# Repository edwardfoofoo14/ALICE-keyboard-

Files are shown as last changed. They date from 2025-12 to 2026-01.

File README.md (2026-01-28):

# SELENE

This is my SELENE, my project for the Blueprint Hack Club event!

The board uses an ALICE layout with added F rows, it is inspired by Dante from Devil May Cry (my favourite character). It uses a stacked acrylic format which I took inspiration from Adelheid, and Arisu which are both Alice keyboards. The stacked acrylic mentioned is a collection of 10, 3mm, A3 sized, machine cut acrylic plates screwed together, I chose this method in particular because the material will generate a "clackier" sound profile and is also more cost effective that other methods.

---

## Files Included
- PCB  
- Plate  
- Case 
- Simulation code and diagram 

Cool graphics showing each layers of the acrylic
kbgif

---

## PCB

Note: it is quite rudimentary because a keyboard isn't the most complicated thing in the world.

PCB Layout

Overview of the schematic

Schematic

---

## Plate

Note: The plate will be shinier in real life :D

Plate

---

## Case

Case

Note:
- Both the plate and case are provided as DXF files, and dimensions may still be adjusted.

---

## Parts Required
- 10x A3 acrylic sheets (3 mm)
- 1x A3 acrylic sheet (2 mm)
- Poron gaskets (3 mm thickness)
- 6x M5 x 35 mm screws
- 6x M5 nuts

---

## Cutting Instructions
- Use the DXF files located in the dxf folder
- Cut plates 1 to 10 from the 3 mm acrylic
- Cut the main plate from the 2 mm acrylic

---

## Assembly Instructions
1. Stack the numbered plates from bottom to top  
2. On plate 2:
   - Secure the USB C breakout board
   - Add Poron gaskets to the protruding sections
3. Place the keyboard plate on top with the PCB already attached (switches snapped into respective holes in the plate)
4. Apply adhesive Poron gaskets again on the top surface
5. Continue stacking plates 3 to 10
6. Secure the entire assembly using the screws, ideally with the nuts on the bottom side. The screws should skewer through the whole width of the keyboard.

---

## Important Notes
An important thing to note would be to afix your stabilisers switches to the plate and PCB before assembly as there is nothing to join the pcb and plate together. Also for plate 2 and 10 there are my personal designs, you can add your own if you want or just make sure you remove it if you don't want my design.

---

## Simulation
The Wokwi simulation follows the exact ESP32 pinout shown in the KiCad schematic:

https://github.com/user-attachments/assets/cd191653-9d43-4bff-b9b6-e710f8436f32

---

## Wiring
The wiring is extremely simple. Just connect the cables between the keyboard PCB and USB-C breakout board following the labels on the silkscreen

Depending on the type of USB-C breakout boards used, CC1 and CC2 pins may or may not require 5.1kΩ pull down. The Sparkfun boards have two resistors that are already soldered.
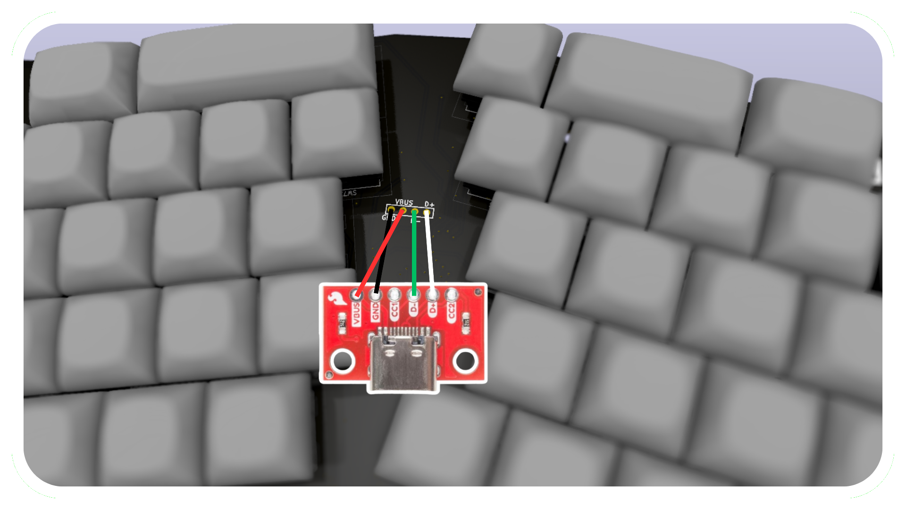
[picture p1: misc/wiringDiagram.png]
Wiring Diagram


## Bill of Material

Note: The prices in USD are converted as of 7 January 2026 and prices may fluctuate

| Category | Item Name | Part Number / File Name | Link | Vendor | Quantity | Total Price (USD) |
|---|---|---|---|---|---|---|
| Electronics | ESP32-S3-WROOM-1-N16-R2 | ESP32-S3-WROOM-1-N16-R2 | [Link](https://shopee.com.my/ESP32-S3-ESP32-S3-WROOM-1-1U-ESP32-S3-MINI-1U-4MB-8MB-16MB-N4-N4R2-N4R8-N8-N8R2-N8R8-N16-N16R2-N16R8-WiFi-Ble-5.0-Module-i.1649836180.431738840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) | Shopee | 1x | 6.53 |
| Electronics | SK6812 MINI-E | | [Link](https://shopee.com.my/100PCS-SK6812-MINI-E-RGB-(Similar-WS2812B)-SK6812-3228-SMD-Pixels-LED-Chip-Individually-Addressable-Full-Color-DC-5V-i.201200871.29163981070) | Shopee | 100x | 2.80 |
| Electronics | 1206 100nF Capacitor | | [Link](https://shopee.com.my/100pcs-1206-3216-SMD-Chip-Ceramic-Capacitor-1NF-2.2NF-10NF-22NF-100NF-1uF-2.2uF-4.7uF-10uF-22uF-47uF-100uF-6.3V-10V-16V-25V-50V-i.1649836180.51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) | Shopee | 100x | 0.35 |
| Electronics | Hotswap Sockets | | [Link](https://shopee.com.my/redsunaa-Hot-Swap-Socket-For-Kailh-CPG151101S11-for-Mechanical-Keyboard-Switch-Pcb-Base-i.1336977141.27113734076) | Shopee | 100x | 9.95 |
| Electronics | USB-C Breakout Board | | [Link](https://shopee.com.my/Pcbfun-USB-Type-C-Connector-Board-DIY-3.1-Serial-Basic-Breakout-Female-Connector-Type-C-Breakout-Board-for-Data-Line-Wire-Cable-Transfer-i.1754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) | Shopee | 1x | 0.80 |
| Production | PCB | gerbers.zip | | JLCPCB | 1x | 23.00 |
| Fasteners | M5*35mm Hex Screws | | [Link](https://shopee.com.my/Button-Head-Screw-Black-304-Stainless-Steel-SHINY-SURFACE-Allen-Bolt-DIN7380-Skru-Ellenkey-Hex-Socket-Button-Head-Screw-ISO7380-SUS-Black-304-S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) | Shopee | 10x | 3.55 |
| Fasteners | M5 Nuts | | [Link](https://shopee.com.my/-HKH-Hexagon-Nut-M2-M2.5-M2.6-M3-M3.5-M4-M5-M6-M8-M10-M12-Black-arbon-Steel-Hexagon-Nut-Screw-Cap-i.1435573023.27623483039) | Shopee | 50x | 0.55 |
| Misc | Stabilisers | | [Link](https://shopee.com.my/Kelowna-Link-Studio-PCB-Screw-in-Stabilizers-Mechanical-Keyboard-i.71961069.12272946569) | Shopee | 1x | 7.40 |
| Misc | Gaskets | | [Link](https://shopee.com.my/Gasket-Strip-Poron-black-only-i.1034684783.25753214842) | Shopee | 1x | 3.20 |
| Misc | Switches | | [Link](https://shopee.com.my/Outemu-Honey-Peach-Silent-Linear-Switch-for-Mechanical-Keyboards-i.72068395.11794425429) | Shopee | 82x | 22.90 |
| Shipping | PCB Shipping | E-POST | | JLCPCB | 1x | 9.87 |
| Shipping | Switches Shipping | SPX Express International | | Shopee | 1x | 0.00 |
| Shipping | Electronics Shipping | SPX Express International | | Shopee | 4x | 5.20 |
| Shipping | Fasteners Shipping | SPX Express International | | Shopee | 2x | 2.60 |
| Shipping | Gaskets Shipping | SPX Express | | Shopee | 1x | 1.30 |
| | | | *Do take note this list excludes some parts that hack club isn't paying for, required parts to build the keyboard is in the excluded list in the readme* | | **Grand Total:** | **100.00** |

## Excluded Items

- Keycaps
- Diodes
- 4.7k resistor
- 10uF capacitors
- A3 3mm acrylic plates

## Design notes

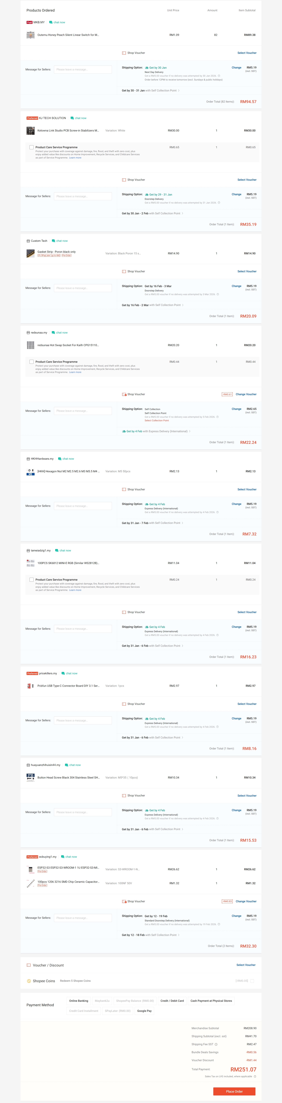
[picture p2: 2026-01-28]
cartScreenshots/shopeeCart.jpeg

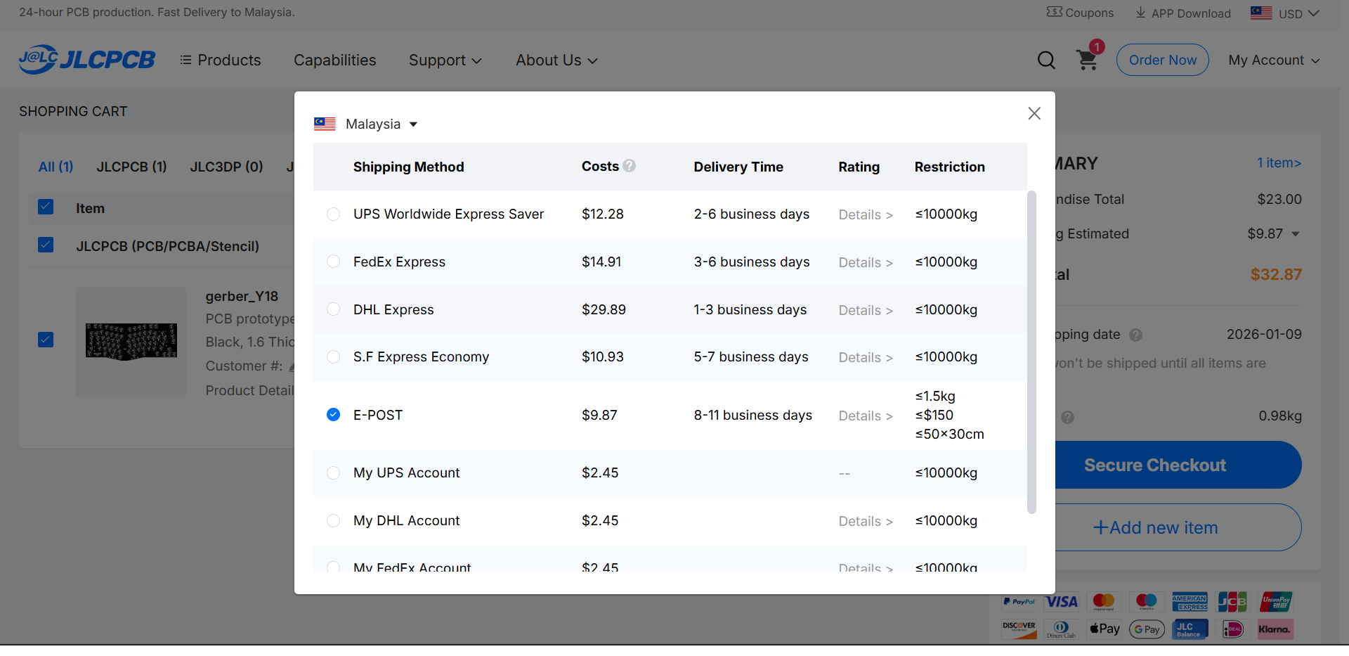
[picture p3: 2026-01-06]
cartScreenshots/shippingOptions.png

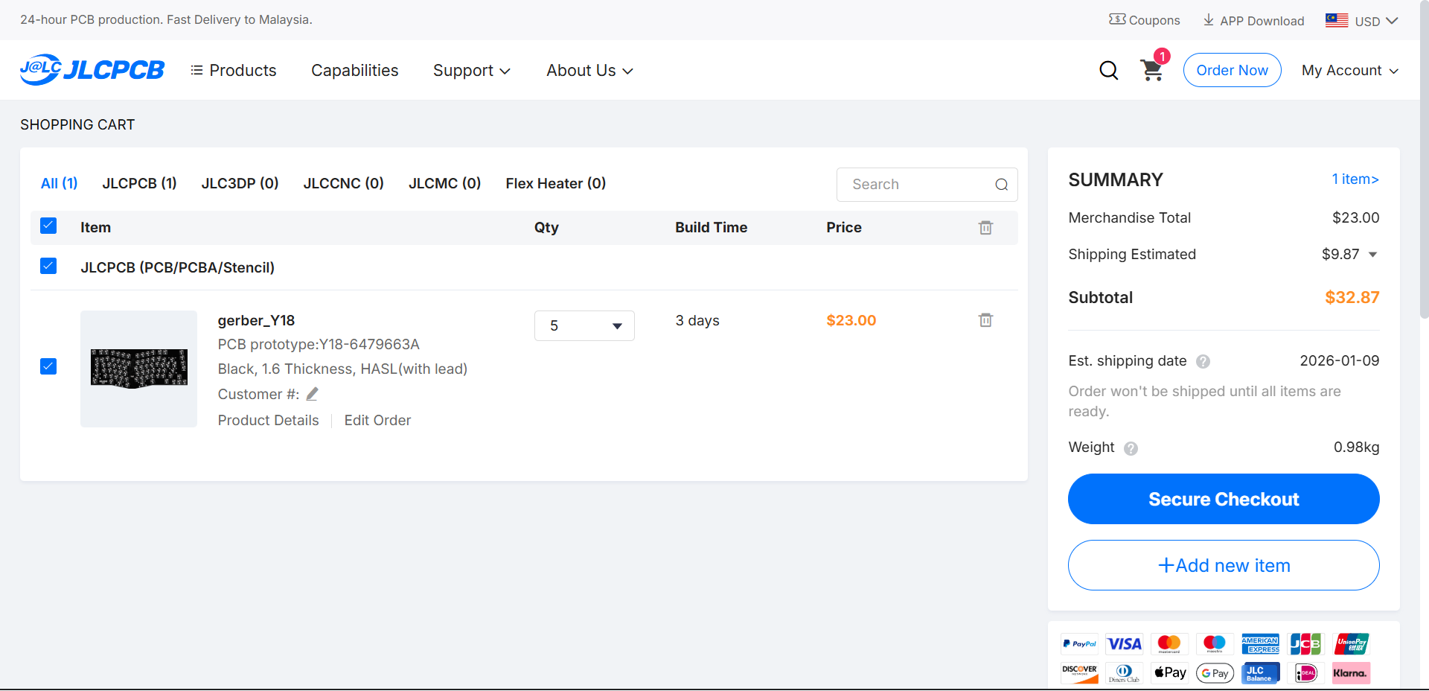
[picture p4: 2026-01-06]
cartScreenshots/JLCPCBCart.png

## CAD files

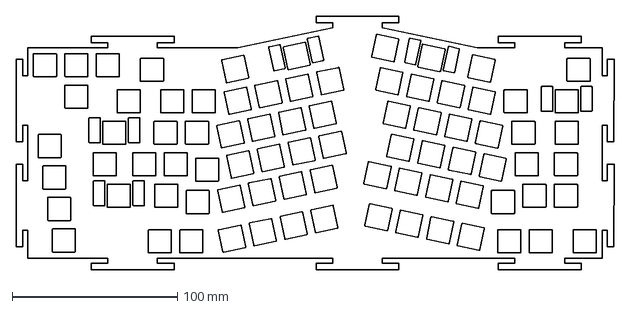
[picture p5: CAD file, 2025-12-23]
production/LaserCut/MAINPLATE.dxf
361.9 x 153.3 mm

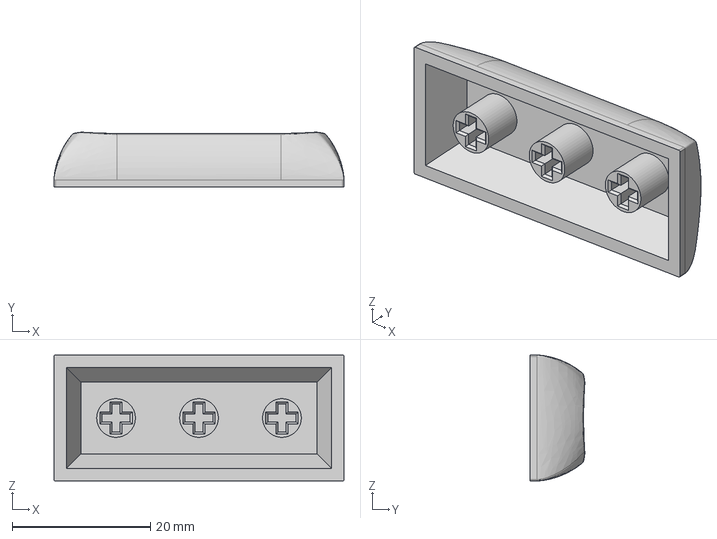
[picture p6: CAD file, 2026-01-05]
PCB/3d/keycap/DSA_2.25u.step
42.0 x 7.91 x 18.2 mm

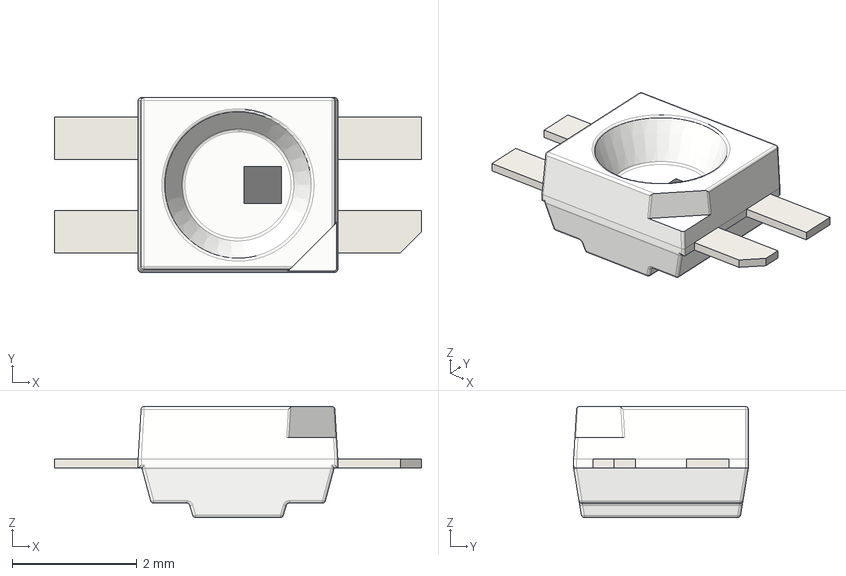
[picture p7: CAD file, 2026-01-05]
PCB/3d/LED_SK6812MINI-E.step
5.88 x 2.80 x 1.78 mm

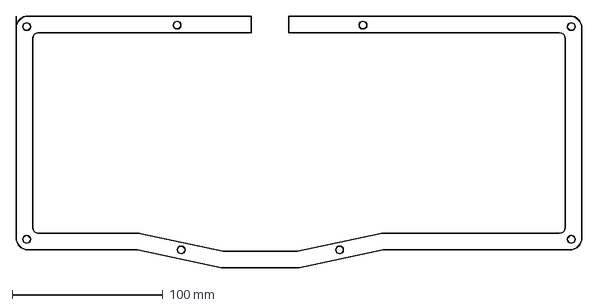
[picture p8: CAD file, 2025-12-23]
production/LaserCut/plate 3.dxf
375.0 x 167.0 mm

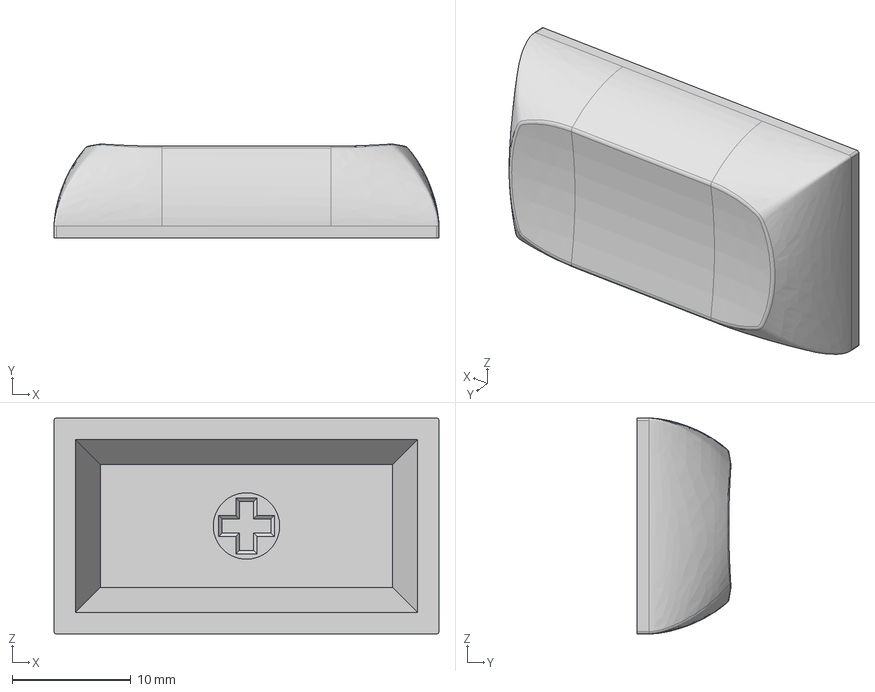
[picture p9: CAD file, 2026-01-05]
PCB/3d/keycap/DSA_1.75u.step
32.5 x 7.91 x 18.2 mm

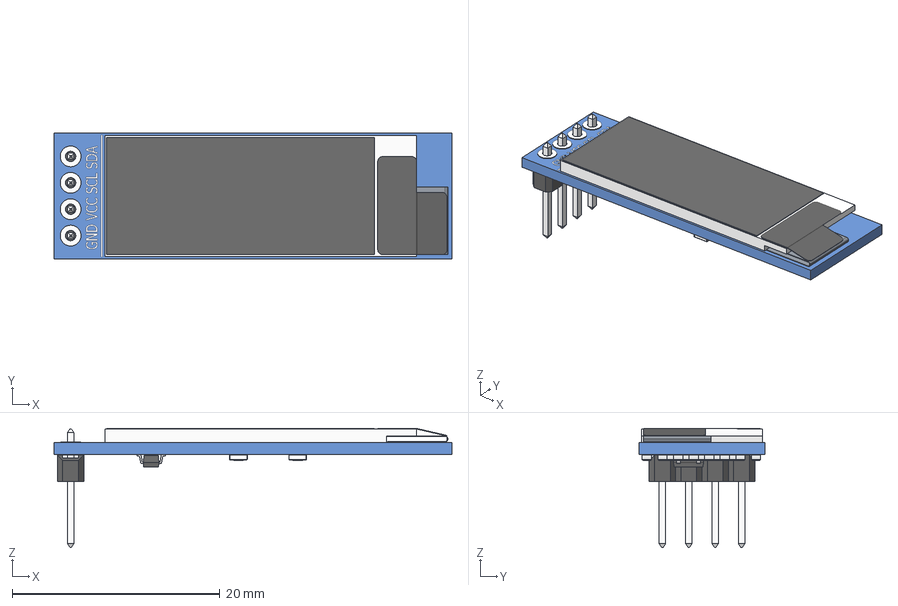
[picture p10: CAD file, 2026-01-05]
PCB/3d/OLED_0.91_128x32.stp
38.3 x 12.1 x 11.5 mm
OLED_0.91_128x32
Pin Header 4 x 1 TH 2.54mm Pitch
RESC-0603 x 13
2SD0601A

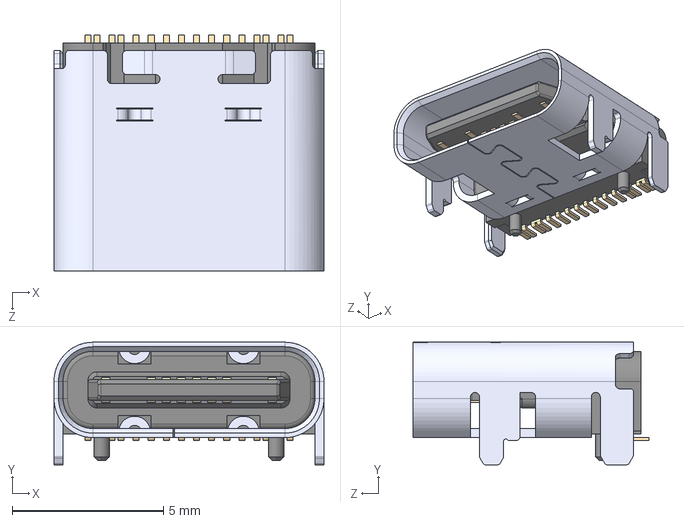
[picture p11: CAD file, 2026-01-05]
PCB/3d/CQ-USB-C16PSMT01.step
8.94 x 4.06 x 7.81 mm

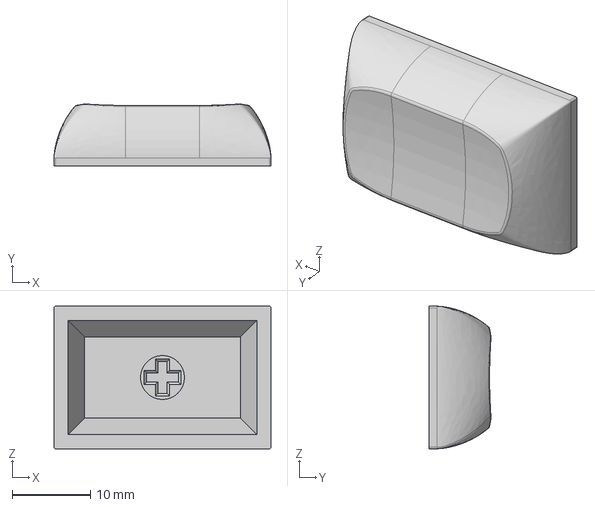
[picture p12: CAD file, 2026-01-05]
PCB/3d/keycap/DSA_1.5u.step
27.7 x 7.91 x 18.2 mm

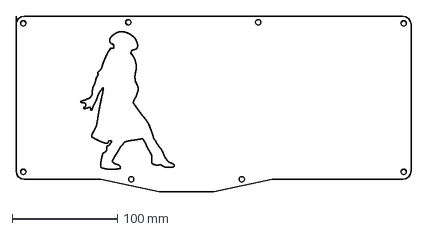
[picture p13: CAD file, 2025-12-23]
production/LaserCut/plate 2.dxf
375.0 x 167.0 mm

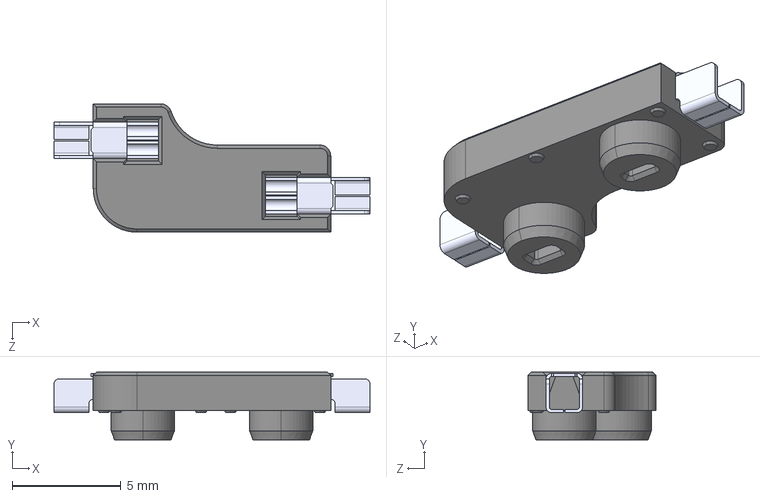
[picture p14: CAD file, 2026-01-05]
PCB/3d/kailhSocket.STEP
14.5 x 3.10 x 5.89 mm

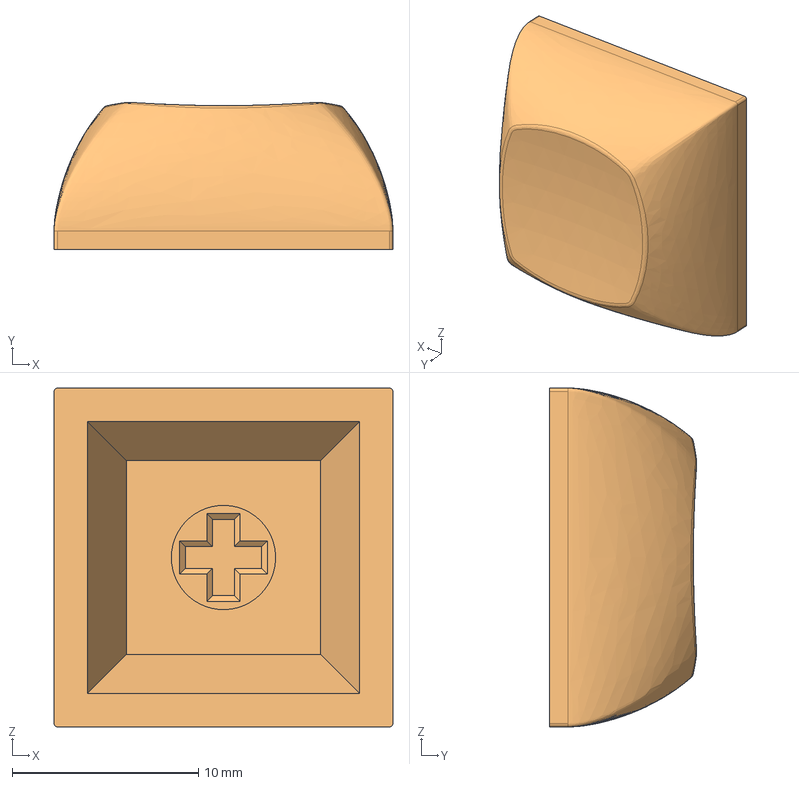
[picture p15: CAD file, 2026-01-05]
PCB/3d/keycap/DSA_1u.step
18.2 x 7.91 x 18.2 mm

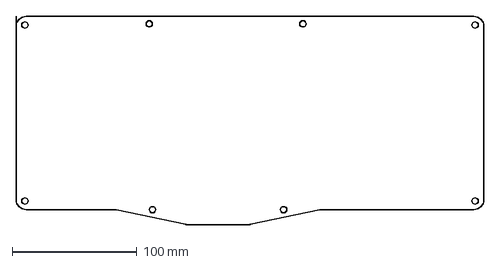
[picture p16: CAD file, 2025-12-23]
production/LaserCut/plate 1.dxf
375.0 x 167.0 mm

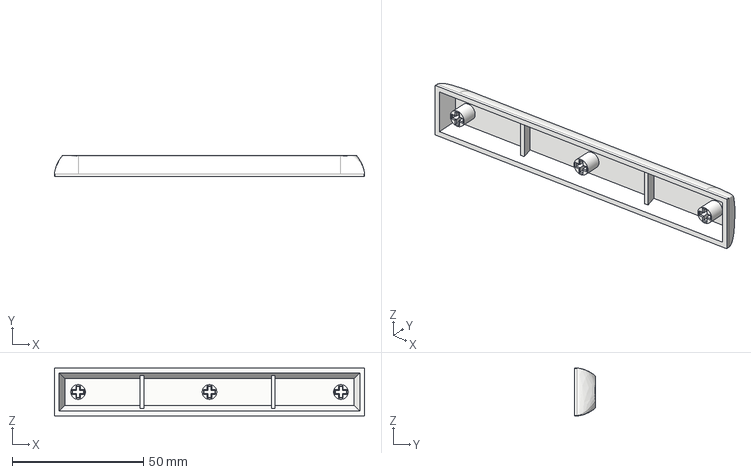
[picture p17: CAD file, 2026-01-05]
PCB/3d/keycap/DSA_6.25u.step
118.0 x 8.00 x 18.2 mm

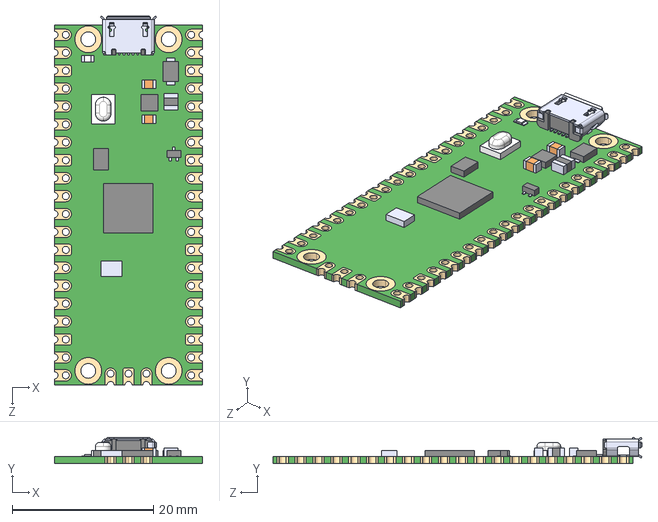
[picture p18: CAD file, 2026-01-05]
PCB/3d/RASPBERRY_PI_PICO.step
21.0 x 3.73 x 52.3 mm

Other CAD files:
production/LaserCut/plate 6.dxf
PCB/3d/keycap/DSA_2u.step
PCB/3d/switch.step
PCB/3d/TS-1187A-B-A-B.step
PCB/3d/keycap/DSA_1.25u.step
PCB/3d/keycap/DSA_2.75u.step
PCB/3d/stabilizer.STEP
production/LaserCut/plate 10.dxf
production/LaserCut/plate 7.dxf
production/LaserCut/plate 8.dxf
production/LaserCut/plate 9.dxf

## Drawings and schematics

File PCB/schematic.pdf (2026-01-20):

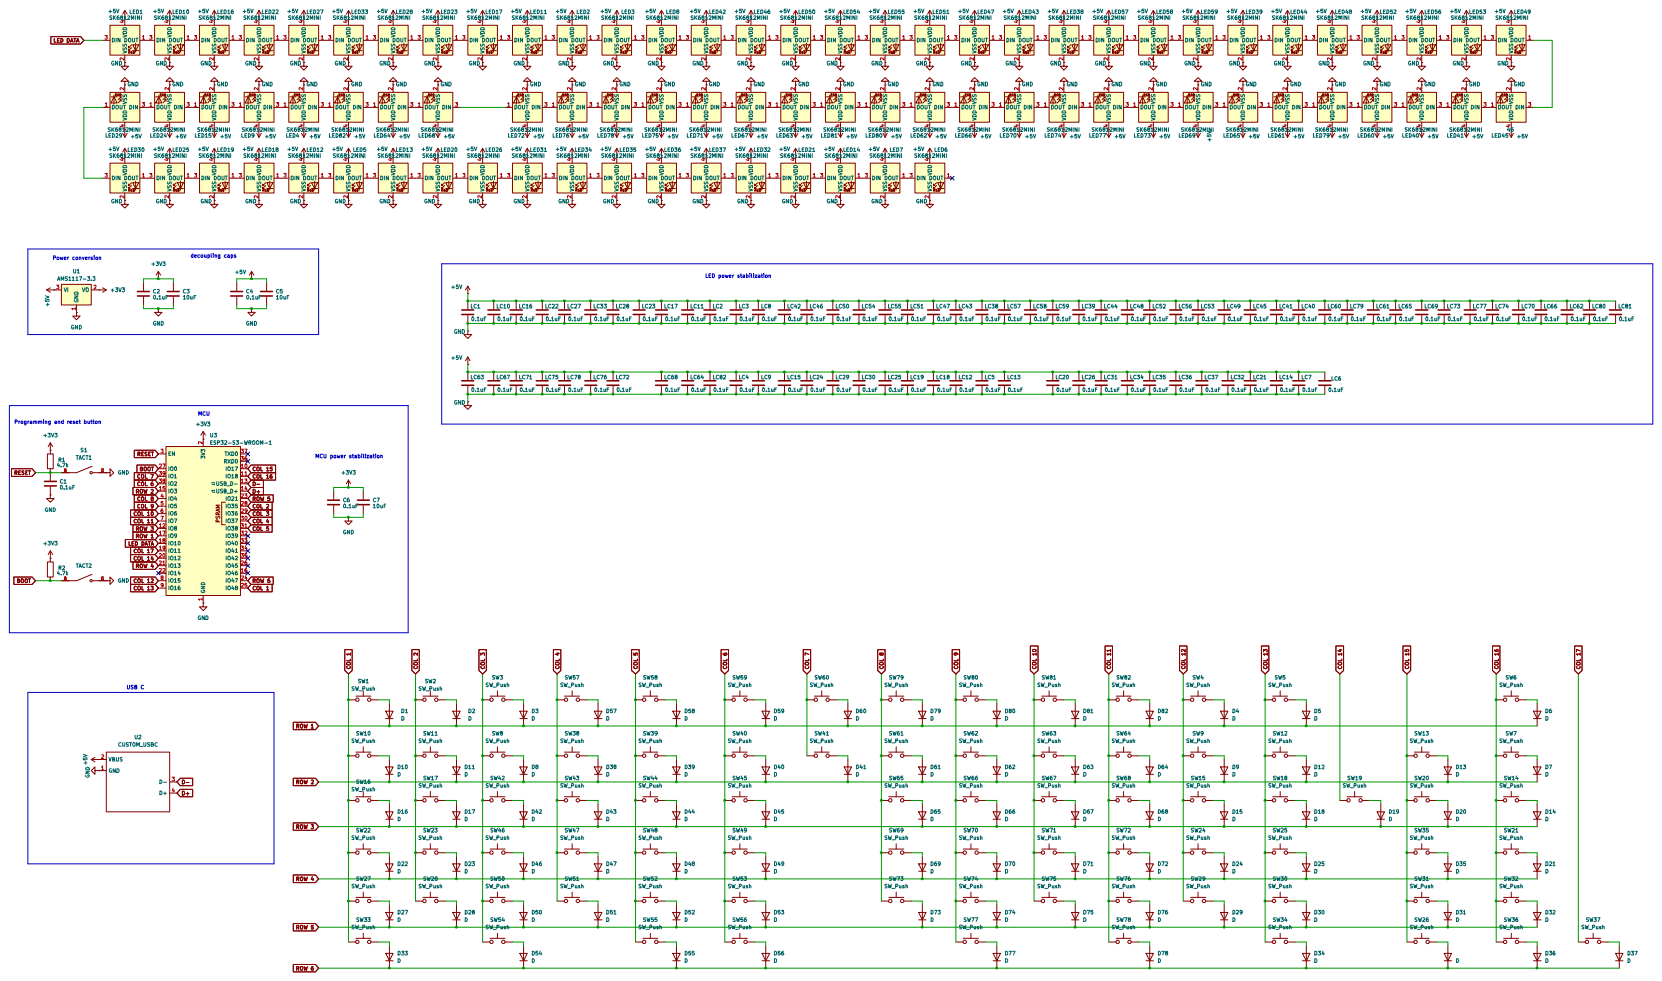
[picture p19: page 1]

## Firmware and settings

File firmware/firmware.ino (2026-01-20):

#include <Arduino.h>
#include <USB.h>
#include <USBHIDKeyboard.h>
#include <USBCDC.h>

const uint16_t SCAN_RATE_HZ = 1000;
const uint16_t DEBOUNCE_MS = 5;
#define LED_PIN 10
#define NUM_ROWS 6
#define NUM_COLS 17

const uint8_t COL_PINS[NUM_COLS] = { 
  48, 35, 36, 37, 38, 2, 1, 4, 5, 6, 7, 15, 16, 12, 17, 18, 11 
};

const uint8_t ROW_PINS[NUM_ROWS] = { 
  9, 3, 8, 13, 21, 47 
};


#define FN_KEY_VAL 0xFF  // internal marker
const uint8_t KEY_MAP[NUM_ROWS][NUM_COLS] = {
  // ROW1 (GPIO9)
  {KEY_ESC, KEY_F1, KEY_F2, KEY_F3, KEY_F4, KEY_F5, KEY_F6, KEY_F7, KEY_F8, KEY_F9, KEY_F10, KEY_F11, KEY_F12, 0, 0, KEY_DELETE, 0},
  
  // ROW2 (GPIO3)
  {'`', '1', '2', '3', '4', '5', '6', '7', '8', '9', '0', '-', '=', 0, KEY_BACKSPACE, KEY_PAGE_UP, 0},
  
  // ROW3 (GPIO8)
  {KEY_TAB, 'q', 'w', 'e', 'r', 't', 0, 'y', 'u', 'i', 'o', 'p', '[', ']', '\\', KEY_PAGE_DOWN, 0},
  
  // ROW4 (GPIO13)
  {KEY_CAPS_LOCK, 'a', 's', 'd', 'f', 'g', 0, 'h', 'j', 'k', 'l', ';', '\'', 0, KEY_RETURN, 0xCE, 0},
  
  // ROW5 (GPIO21)
  {KEY_LEFT_SHIFT, 'z', 'x', 'c', 'v', 'b', 0, 'n', 'm', ',', '.', '/', KEY_RIGHT_ALT, 0, KEY_RIGHT_SHIFT, KEY_UP_ARROW, 0},
  
  // ROW6 (GPIO47)
  {KEY_LEFT_CTRL, 0, KEY_LEFT_ALT, 0, ' ', KEY_LEFT_GUI, 0, 0, ' ', 0, KEY_RIGHT_CTRL, 0, FN_KEY_VAL, 0, KEY_LEFT_ARROW, KEY_DOWN_ARROW, KEY_RIGHT_ARROW}
};

USBHIDKeyboard Keyboard;

uint8_t keyState[NUM_ROWS][NUM_COLS] = {0}; 
uint8_t prevKeyState[NUM_ROWS][NUM_COLS] = {0};
uint32_t lastScanTime = 0;
uint32_t scanIntervalUs;
void scanMatrix();
void processKeyChanges();


void setup() {
  Serial.begin(115200);
  // Keep LED pin pulled low when not in use
  pinMode(LED_PIN, OUTPUT);
  digitalWrite(LED_PIN, LOW);
  scanIntervalUs = 1000000 / SCAN_RATE_HZ;
  
  for (uint8_t col = 0; col < NUM_COLS; col++) {
    pinMode(COL_PINS[col], OUTPUT);
    digitalWrite(COL_PINS[col], LOW);
  }
  
  for (uint8_t row = 0; row < NUM_ROWS; row++) {
    pinMode(ROW_PINS[row], INPUT_PULLDOWN);
  }

  Keyboard.begin();
  USB.begin();
  delay(100);
  lastScanTime = micros();
}

void loop() {
  uint32_t currentTime = micros();
  if (currentTime - lastScanTime >= scanIntervalUs) {
    lastScanTime = currentTime;
    scanMatrix();
    processKeyChanges();
  }
}


void scanMatrix() {
  for (uint8_t col = 0; col < NUM_COLS; col++) {
    digitalWrite(COL_PINS[col], HIGH);
    delayMicroseconds(4); // Wait till signal stabilize due to line capacitance
    
    for (uint8_t row = 0; row < NUM_ROWS; row++) {
      bool pressed = digitalRead(ROW_PINS[row]);
      
      if (pressed) {
        // debouncing increment counter limited at 255 to prevent overflow
        if (keyState[row][col] < 255) keyState[row][col]++;
      } else {
        keyState[row][col] = 0;
      }
    }
    digitalWrite(COL_PINS[col], LOW);
  }
}

void processKeyChanges() {
  uint8_t debounceThreshold = (DEBOUNCE_MS * SCAN_RATE_HZ) / 1000;
  if (debounceThreshold < 1) debounceThreshold = 1;
  
  for (uint8_t row = 0; row < NUM_ROWS; row++) {
    for (uint8_t col = 0; col < NUM_COLS; col++) {
      uint8_t keyCode = KEY_MAP[row][col];
      if (keyCode == 0) continue;
      bool currentPressed = (keyState[row][col] >= debounceThreshold);
      bool previousPressed = prevKeyState[row][col];
      
      if (currentPressed && !previousPressed) {
        if (keyCode == FN_KEY_VAL) {
            // FN placeholder for LED
            Serial.println(F("FN pressed"));
        } else {
            Keyboard.press(keyCode);
        }
        prevKeyState[row][col] = 1;
      }
      else if (!currentPressed && previousPressed) {
        if (keyCode == FN_KEY_VAL) {
        } else {
            Keyboard.release(keyCode);
        }
        prevKeyState[row][col] = 0;
      }
    }
  }
}

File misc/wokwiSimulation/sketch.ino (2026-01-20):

#include <Wire.h>
#include <Adafruit_GFX.h>
#include <Adafruit_SSD1306.h>

#define SCREEN_WIDTH 128
#define SCREEN_HEIGHT 64
#define OLED_SCL_PIN 43
#define OLED_SDA_PIN 44

Adafruit_SSD1306 display(SCREEN_WIDTH, SCREEN_HEIGHT, &Wire, -1);

const int COL_COUNT = 17;
const int ROW_COUNT = 6;

int colPins[COL_COUNT] = {48, 35, 36, 37, 38, 2, 1, 4, 5, 6, 7, 15, 16, 12, 17, 18, 11};
int rowPins[ROW_COUNT] = {9, 3, 8, 13, 21, 47};

unsigned long lastScanTime = 0;
const unsigned long SCAN_INTERVAL_MICROS = 2000; 

bool lastWasPressed = false;
int lastColIndex = -1;
int lastRowIndex = -1;

void setup() {
  Wire.begin(OLED_SDA_PIN, OLED_SCL_PIN);
  if(!display.begin(SSD1306_SWITCHCAPVCC, 0x3C)) { 
    for(;;);
  }
  display.clearDisplay();
  display.setTextSize(1);
  display.setTextColor(SSD1306_WHITE);
  display.setCursor(0,0);
  display.println("Idle");
  display.display();
  for (int i = 0; i < COL_COUNT; i++) {
    pinMode(colPins[i], OUTPUT);
    digitalWrite(colPins[i], LOW);
  }
  for (int i = 0; i < ROW_COUNT; i++) {
    pinMode(rowPins[i], INPUT_PULLDOWN);
  }
}

void loop() {
  unsigned long currentTime = micros();
  if (currentTime - lastScanTime >= SCAN_INTERVAL_MICROS) {
    lastScanTime = currentTime;
    scanMatrix();
  }
}

void scanMatrix() {
  bool currentIsPressed = false;
  int currentCol = -1;
  int currentRow = -1;
  for (int c = 0; c < COL_COUNT; c++) {
    digitalWrite(colPins[c], HIGH);
    delayMicroseconds(5); 
    for (int r = 0; r < ROW_COUNT; r++) {
      if (digitalRead(rowPins[r]) == HIGH) {
        currentIsPressed = true;
        currentCol = c;
        currentRow = r;
      }
    }
    digitalWrite(colPins[c], LOW);
  }

  bool stateChanged = false;
  
  if (currentIsPressed != lastWasPressed) {
    stateChanged = true;
  }
  else if (currentIsPressed && (currentCol != lastColIndex || currentRow != lastRowIndex)) {
    stateChanged = true;
  }
  if (stateChanged) {
    display.clearDisplay();
    display.setCursor(0, 0);
    display.setTextSize(1);

    if (currentIsPressed) {
      display.println("Key Pressed:");
      display.setTextSize(2);
      display.setCursor(0, 20);
      display.print("C");
      display.print(currentCol);
      display.print(" R");
      display.print(currentRow);
      display.setTextSize(1);
      display.setCursor(0, 45);
      display.print("GPIO: ");
      display.print(colPins[currentCol]);
      display.print(" / ");
      display.print(rowPins[currentRow]);
    } else {
      display.println("Idle");
    }
    display.display();
  }
  lastWasPressed = currentIsPressed;
  lastColIndex = currentCol;
  lastRowIndex = currentRow;
}

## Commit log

2025-12-23 Create assembly
2025-12-29 Update assembly
2026-01-20 Added firmware
    Fixed acceptable and non critical error with the schematic
    [KeyboardMapping.csv, thisoneinitiald.kicad_sch]
2026-01-23 Added wiring diagram
2026-01-28 Updated bom
    [bom.csv]
2026-01-28 fix bom again
    [bom.csv]
